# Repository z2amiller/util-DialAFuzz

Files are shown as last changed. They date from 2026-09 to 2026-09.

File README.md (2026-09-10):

# util-DialAFuzz

A plug-in NPN transistor with a dial for hFE. Fuzz circuits are picky about
transistor gain, and modern Si transistors are usually too hot. This board plugs
into a TO-92 socket in place of the transistor and lets you trim the effective
hFE of an ordinary transistor down from its native ~300 to wherever the circuit
sounds right, without hunting for a rare low-gain part.

## How it works

Q2 is the transistor the pedal sees, wired straight across the header. Q1 is
diode-connected in parallel with Q2's base-emitter junction, with the trimmer
in its emitter leg, so it steals a settable share of the base current (a
Widlar split). Effective hFE rises roughly linearly with the trimmer
resistance, and scales with the stage's bias current, so the same setting
reads higher in a 1 mA stage than in a 50 µA one. Trim it in circuit.

LEAK is an optional 2.2M collector-base resistor (leave it off unless wanted).
It injects a small base current that the transistor multiplies, which mimics
the collector leakage of a germanium part, useful when running silicon in a
circuit designed around leaky germanium.

Header order is E, B, C. That matches 2N3904 / 2N5088 style sockets directly;
for a BC-series (C, B, E) socket, plug it in reversed.

## Example: Fuzz Face

PedalPCB's [SiliSmile Fuzz](https://www.pedalpcb.com/product/pcb582/) is a
silicon NPN Fuzz Face with socketed transistors, a good host.

Drop it into the Q1 socket with a BC847 (hFE ~300) and the trimmer covers
roughly hFE 9 at minimum to 240 at maximum. The classic germanium Q1 range of
70 to 100 lands around 200K to 300K. Set it the same way you would bias any
Fuzz Face: adjust for Q2's collector near 4.5 V, or by ear. Nothing is at risk
at either end of the travel; at the bottom the stage just biases wrong.

A companion board, [util-BleedAFuzz](https://github.com/z2amiller/util-BleedAFuzz),
does the same job with a single transistor and a base-emitter bleed, which
suits collector-feedback fuzzes better.

## Gerbers

[GERBER-util-DialAFuzz.zip](GERBER-util-DialAFuzz.zip) is the JLCPCB-ready
gerber and drill set; no KiCad install needed to order the board. Two SOT-23
BC847s (or whatever ~matched transistors you have), one 0805 resistor (optional),
a 3-pin header and a through-hole 1M trimmer on the back.

## License

Licensed under the **CERN Open Hardware Licence Version 2 – Permissive**
(CERN-OHL-P v2). See [LICENSE](LICENSE) and [NOTICE](NOTICE).

You may make, modify, and sell boards from these files, with no obligation to
publish your changes.

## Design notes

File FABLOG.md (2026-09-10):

# Fab Log

| Date | Board | Rev | Gen | Gerber SHA256 | JLC Order # | Notes |
|---|---|---|---|---|---|---|
| 2026-09-09T19:08 | util-DialAFuzz | 0.2 | 2 | 8c1c58c792e7 | | |

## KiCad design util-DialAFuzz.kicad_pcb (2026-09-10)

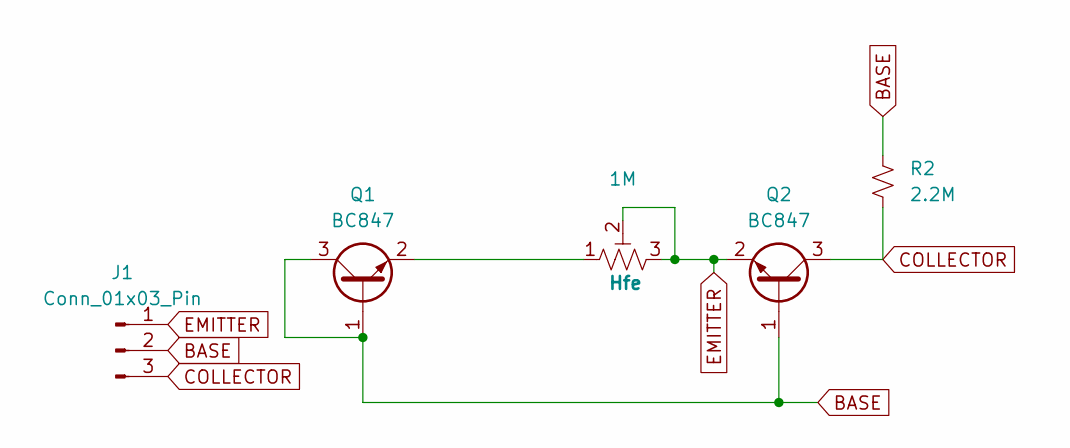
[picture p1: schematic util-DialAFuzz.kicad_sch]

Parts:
J1: Conn_01x03_Pin; PinHeader_1x03_P2.54mm_Vertical
Q1, Q2: BC847; SOT-23_Handsoldering
R2: 2.2M; R_0805_2012Metric_Pad1.20x1.40mm_HandSolder
RV1: 1M; Variable Trimmer

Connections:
BASE: J1.2, Q1.1 (B), Q1.3 (C), Q2.1 (B), R2.2
COLLECTOR: J1.3, Q2.3 (C), R2.1
EMITTER: J1.1, Q2.2 (E), RV1.2, RV1.3
unnamed: Q1.2 (E), RV1.1

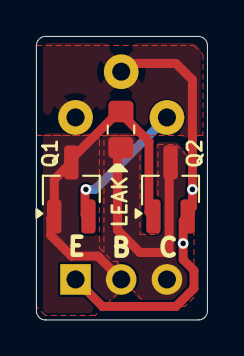
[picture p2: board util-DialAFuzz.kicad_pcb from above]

Board: 2 copper layers, 9.5 x 15.8 mm, 5 parts (1 on the bottom side), 4 nets.

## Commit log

2026-09-09 Initial commit: util-DialAFuzz KiCad project
    [util-DialAFuzz.kicad_pcb, util-DialAFuzz.kicad_sch]
2026-09-09 Set BOARD_STATUS=utility
2026-09-10 Rework as Widlar hFE dial: Q1 diode-connected with 1M emitter trimmer, Q2 pass transistor
    The first draft paralleled Q2 with a rheostat in its collector, which does
    nothing until Q2 saturates and then collapses the effective hFE. Now Q1 is
    diode-connected (C tied to B) with RV1 as a rheostat in its emitter, so it
    steals base drive from Q2 in a Widlar split; effective hFE is roughly linear
    in RV1 and scales with the host stage's bias current (1M reaches ~125 in a
    50 uA collector-feedback stage). R1 dropped: the floor is not a stopper.
    R2 2.2M collector-base (DNP) remains the leakage stand-in.
    [util-DialAFuzz.kicad_pcb, util-DialAFuzz.kicad_sch]
2026-09-10 Remove dangling track stub on the Q1 emitter net
    [util-DialAFuzz.kicad_pcb]
2026-09-10 Add rev 0.1 gerber zip at the repo root for KiCad-free ordering
    Also carries kicad-jlcpcb-tools' own saves to the board and project.db
    from the generation run.
    [util-DialAFuzz.kicad_pcb]
2026-09-10 v0.2: compact double-sided layout, trimmer on the back (9.5 x 15.8 mm)
    Same Widlar circuit as v0.1; the through-hole trimmer moves to the back
    side so the SMD parts and header fit a 5.4 mm shorter board.
    [util-DialAFuzz.kicad_pcb, util-DialAFuzz.kicad_sch]
2026-09-10 Root gerber zip and README updated to rev 0.2 (g2)
2026-09-10 README: what the board does, how, and a Fuzz Face example
